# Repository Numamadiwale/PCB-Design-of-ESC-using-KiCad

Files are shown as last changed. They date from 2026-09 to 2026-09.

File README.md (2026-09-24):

# PCB-Design-of-ESC-using-KiCad
PCB Reverse Engineered Design of an ESC using Kicad ver 9.0
This design is Reverse Engineered design of hakrc 4255 120a single ESC however this design isnt a 100% recreation of the original Design and liberties were taken while designing the device. the design is yet to be Validated by a seasoned PCB designer before it can be considered for production


The Design had no DRC Errors but had "floating island" warnings , take this into strict considerations before attempting anything. Design optimization is highly needed to further minimize the size of the board

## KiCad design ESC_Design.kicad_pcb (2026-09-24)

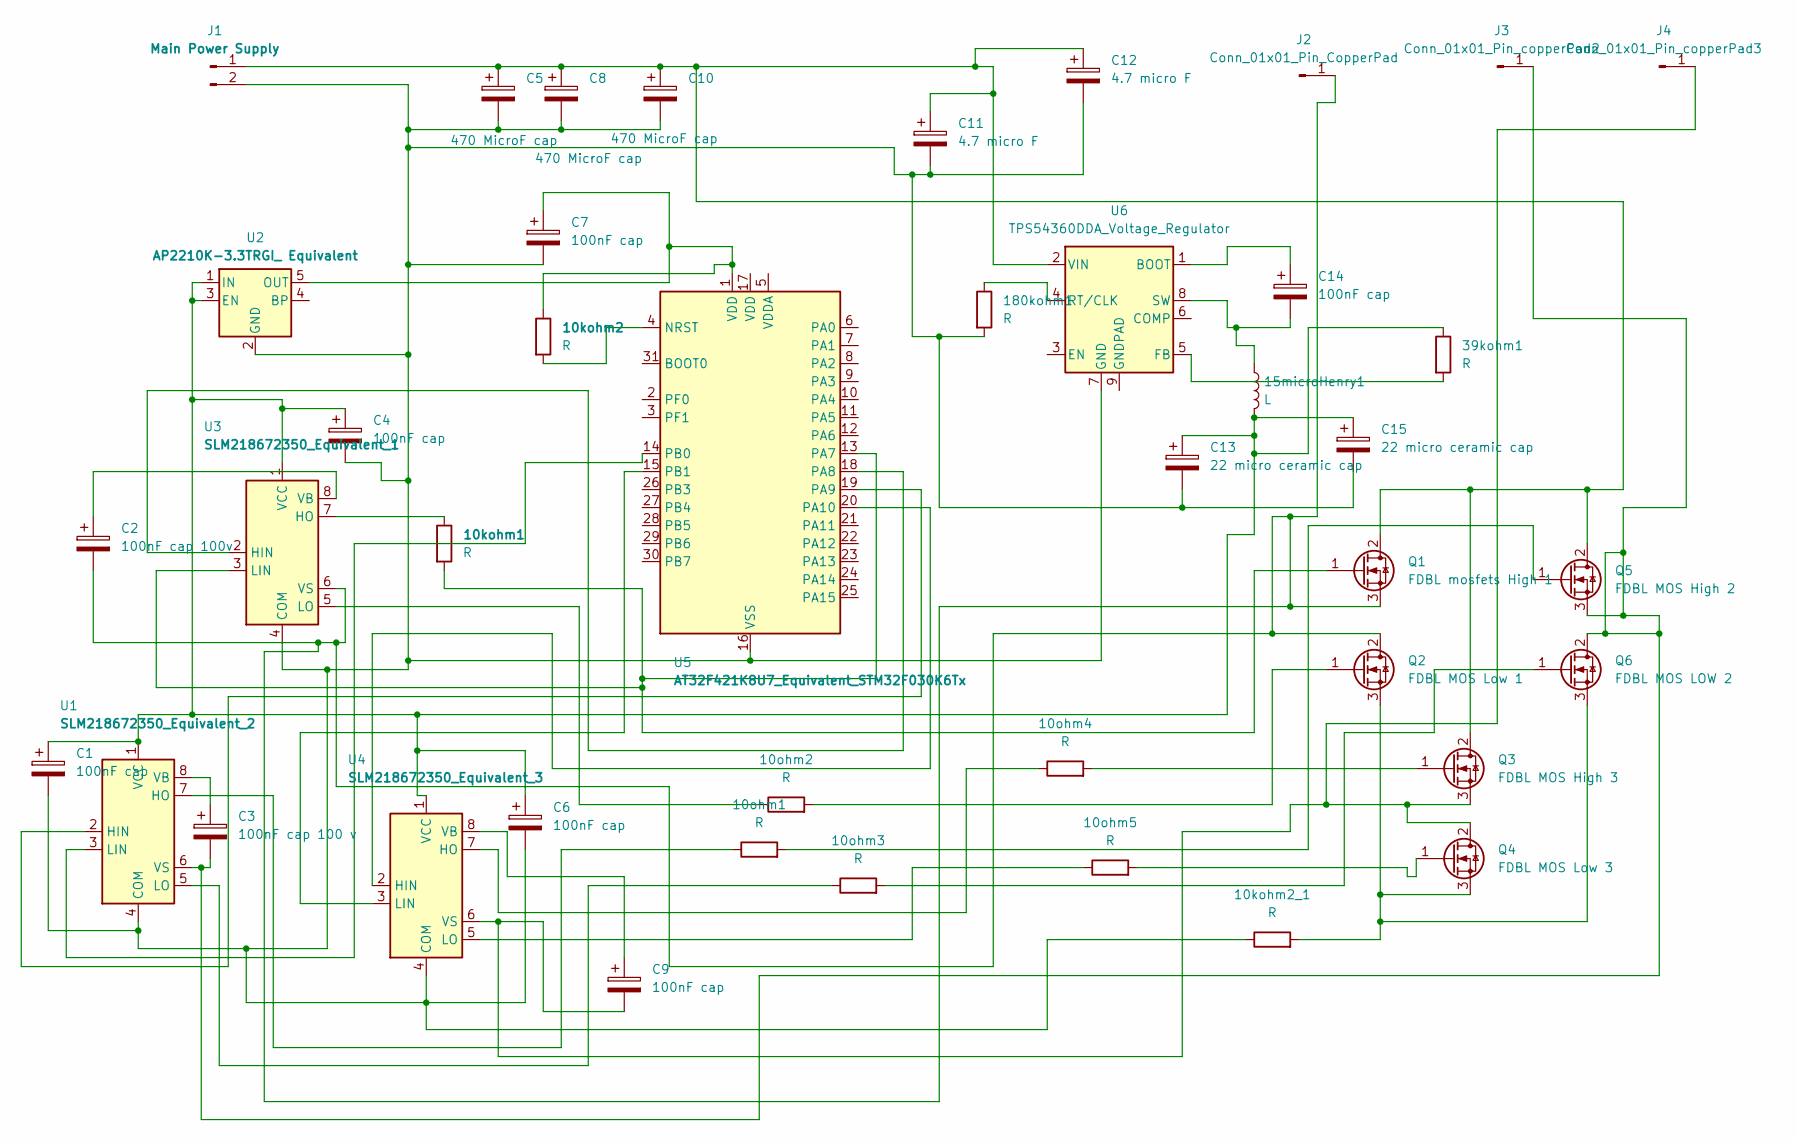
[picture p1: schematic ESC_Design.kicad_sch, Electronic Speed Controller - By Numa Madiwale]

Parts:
10kohm1, 10kohm2, 10kohm2_1, 10ohm1, 10ohm2, 10ohm3, 10ohm4, 10ohm5, 39kohm1, 180kohm1: R; R_0603_1608Metric
15microHenry1: L; L_12x12mm_H8mm
C1, C4, C6, C7, C9, C14: 100nF cap; C_0805_2012Metric
C2: 100nF cap 100v; C_0805_2012Metric
C3: 100nF cap 100 v; C_0805_2012Metric
C5, C8, C10: 470 MicroF cap; C_0805_2012Metric
C11, C12: 4.7 micro F; C_0805_2012Metric
C13, C15: 22 micro ceramic cap; C_1210_3225Metric
J1: Main Power Supply; AMASS_XT60-M_1x02_P7.20mm_Vertical
J2: Conn_01x01_Pin_CopperPad; TestPoint_Pad_4.0x4.0mm
J3: Conn_01x01_Pin_copperPad2; TestPoint_Pad_4.0x4.0mm
J4: Conn_01x01_Pin_copperPad3; TestPoint_Pad_4.0x4.0mm
Q1: FDBL mosfets High 1; TO-263-7_TabPin8
Q2: FDBL MOS Low 1; TO-263-7_TabPin8
Q3: FDBL MOS High 3; TO-263-7_TabPin8
Q4: FDBL MOS Low 3; TO-263-7_TabPin8
Q5: FDBL MOS High 2; TO-263-7_TabPin8
Q6: FDBL MOS LOW 2; TO-263-7_TabPin8
U1: SLM218672350_Equivalent_2; SOIC-8_3.9x4.9mm_P1.27mm
U2: AP2210K-3.3TRGI_ Equivalent; SOT-23-5
U3: SLM218672350_Equivalent_1; SOIC-8_3.9x4.9mm_P1.27mm
U4: SLM218672350_Equivalent_3; SOIC-8_3.9x4.9mm_P1.27mm
U5: AT32F421K8U7_Equivalent_STM32F030K6Tx; LQFP-32_7x7mm_P0.8mm
U6: TPS54360DDA_Voltage_Regulator; SOIC-8-1EP_3.9x4.9mm_P1.27mm_EP2.29x3mm_ThermalVias

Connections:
unnamed: C5.1, C8.1, C10.1, C11.1, C12.1, J1.1, Q1.2 (D), Q3.2 (D), Q5.2 (D), U6.2 (VIN)
unnamed: 10kohm2_1.1, 180kohm1.2, C1.2, C4.2, C5.2, C6.2, C7.2, C8.2, C10.2, C11.2, C12.2, C13.2, C15.2, J1.2, U1.4 (COM), U2.2 (GND), U3.4 (COM), U4.4 (COM), U5.16 (VSS), U5.32 (VSS), U6.7 (GND)
unnamed: C2.2, J2.1, Q1.3 (S), Q2.2 (D), U3.6 (VS)
unnamed: C3.2, J3.1, Q5.3 (S), Q6.2 (D), U1.6 (VS)
unnamed: C9.2, J4.1, Q3.3 (S), Q4.2 (D), U4.6 (VS)
unnamed: 10kohm1.2, Q1.1 (G), U3.3 (LIN), U5.13 (PA7)
unnamed: 10ohm2.2, Q2.1 (G)
unnamed: 10kohm2_1.2, Q2.3 (S), Q4.3 (S), Q6.3 (S)
unnamed: 10ohm4.2, Q3.1 (G)
unnamed: 10ohm5.2, Q4.1 (G)
unnamed: 10ohm1.2, Q5.1 (G)
unnamed: 10ohm3.2, Q6.1 (G)
unnamed: U1.2 (HIN), U5.19 (PA9)
unnamed: 10ohm1.1, U1.7 (HO)
unnamed: U1.3 (LIN), U5.14 (PB0)
unnamed: 10ohm3.1, U1.5 (LO)
unnamed: C3.1, U1.8 (VB)
unnamed: 15microHenry1.2, 39kohm1.1, C1.1, C4.1, C6.1, C13.1, C15.1, U1.1 (VCC), U2.1 (IN), U2.3 (EN), U3.1 (VCC), U4.1 (VCC)
unnamed: 10kohm2.1, C7.1, U2.5 (OUT), U5.1 (VDD)
unnamed: U3.2 (HIN), U5.18 (PA8)
unnamed: 10kohm1.1, U3.7 (HO)
unnamed: 10ohm2.1, U3.5 (LO)
unnamed: C2.1, U3.8 (VB)
unnamed: U4.2 (HIN), U5.20 (PA10)
unnamed: 10ohm4.1, U4.7 (HO)
unnamed: U4.3 (LIN), U5.15 (PB1)
unnamed: 10ohm5.1, U4.5 (LO)
unnamed: C9.1, U4.8 (VB)
unnamed: 10kohm2.2, U5.4 (NRST)
unnamed: C14.1, U6.1 (BOOT)
unnamed: 39kohm1.2, U6.5 (FB)
unnamed: 180kohm1.1, U6.4 (RT/CLK)
unnamed: 15microHenry1.1, C14.2, U6.8 (SW)

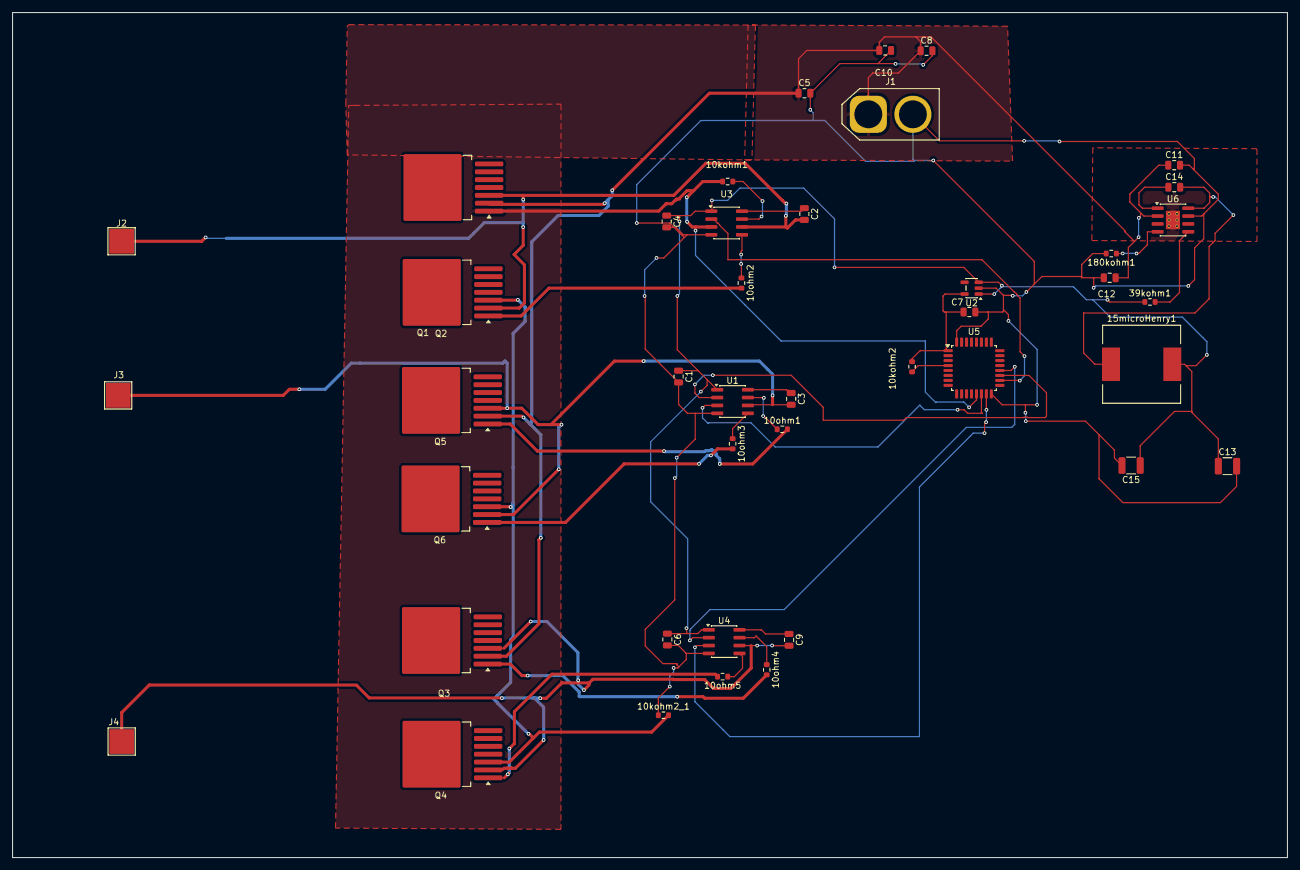
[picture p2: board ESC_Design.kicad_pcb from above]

Board: 2 copper layers, 205.9 x 136.5 mm, 42 parts (0 on the bottom side), 33 nets.
